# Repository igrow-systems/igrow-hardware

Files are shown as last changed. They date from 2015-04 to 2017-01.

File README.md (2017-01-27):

# README #

This README would normally document whatever steps are necessary to get your application up and running.

### What is this repository for? ###

* Quick summary
* Version
* [Learn Markdown](https://bitbucket.org/tutorials/markdowndemo)

### Prototype Hardware ###

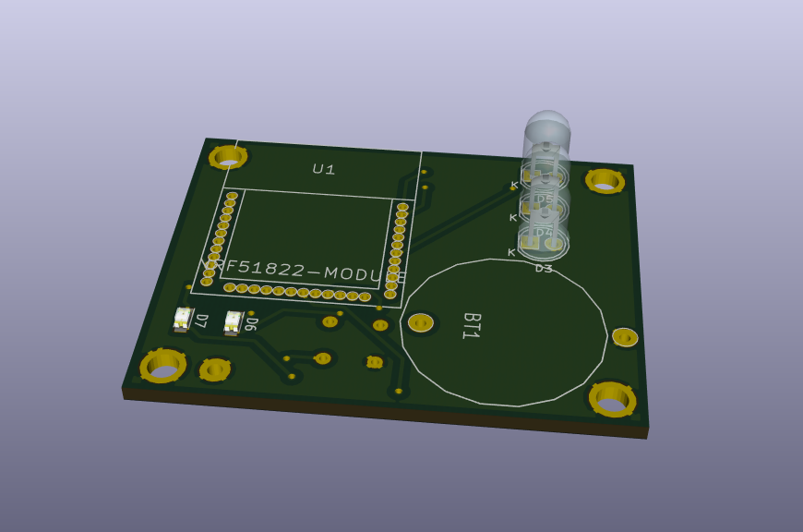
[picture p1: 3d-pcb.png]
PCB 3D View


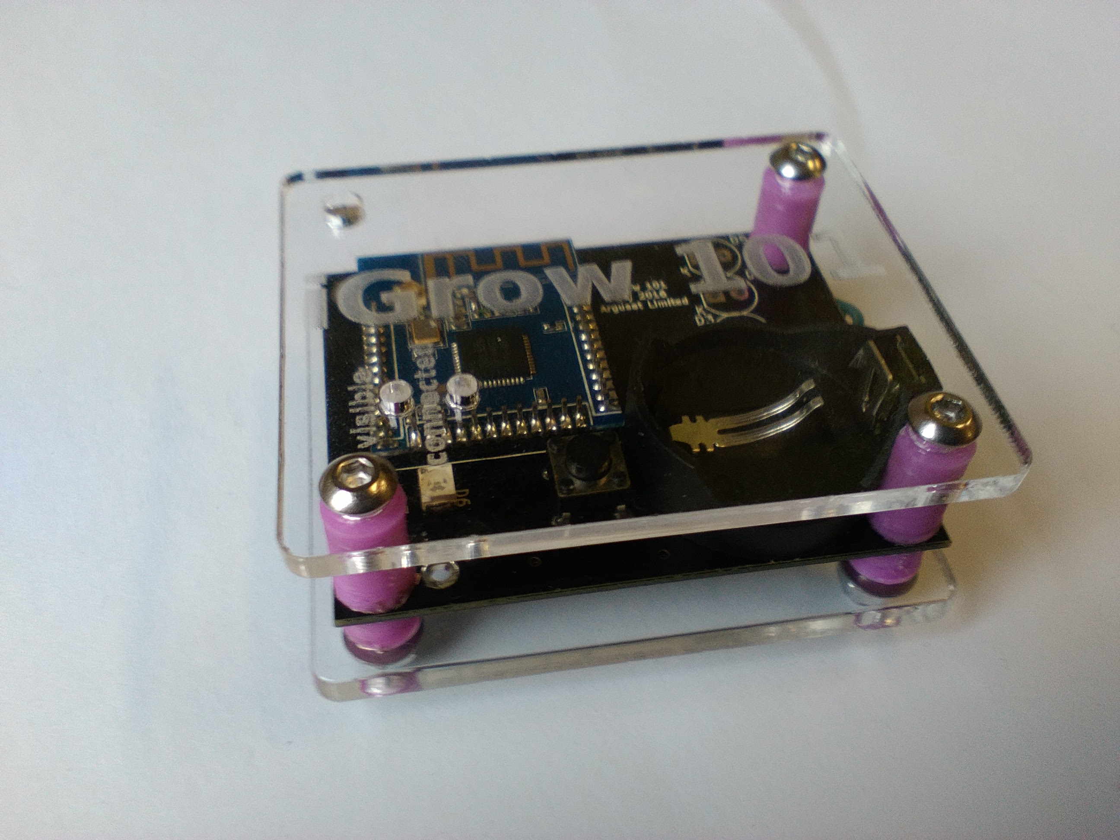
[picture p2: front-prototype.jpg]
Prototype Front


### How do I get set up? ###

* Summary of set up
* Configuration
* Dependencies
* Database configuration
* How to run tests
* Deployment instructions

### Contribution guidelines ###

* Writing tests
* Code review
* Other guidelines

### Who do I talk to? ###

* Repo owner or admin
* Other community or team contact

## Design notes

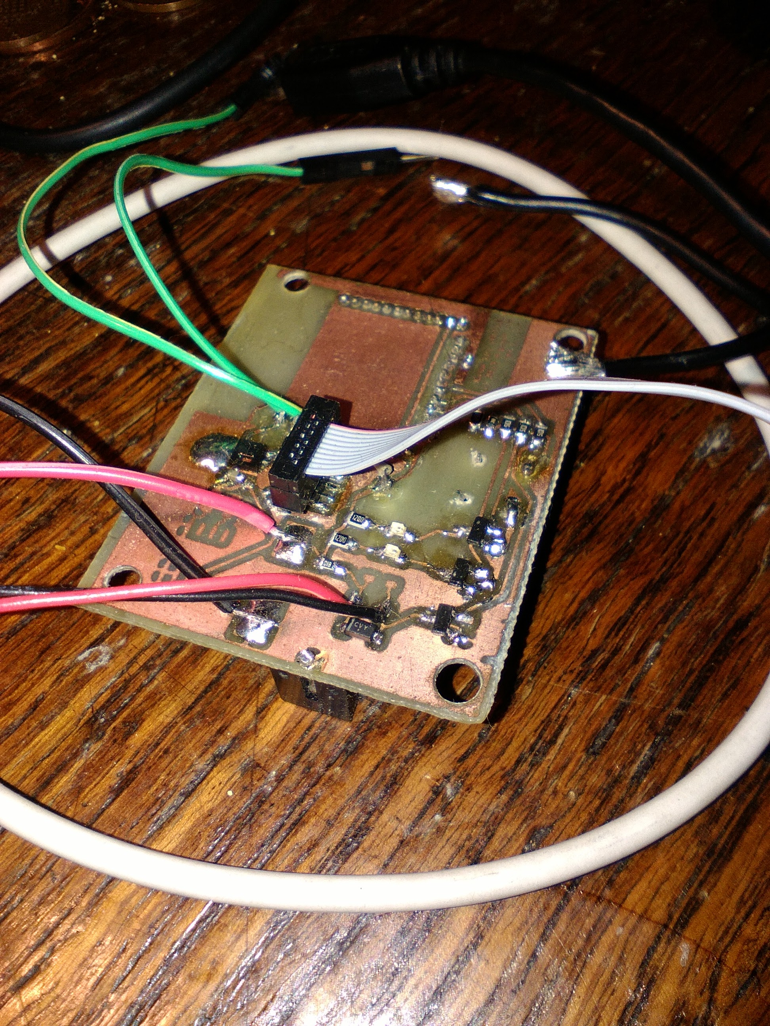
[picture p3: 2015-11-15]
rear-prototype.jpg

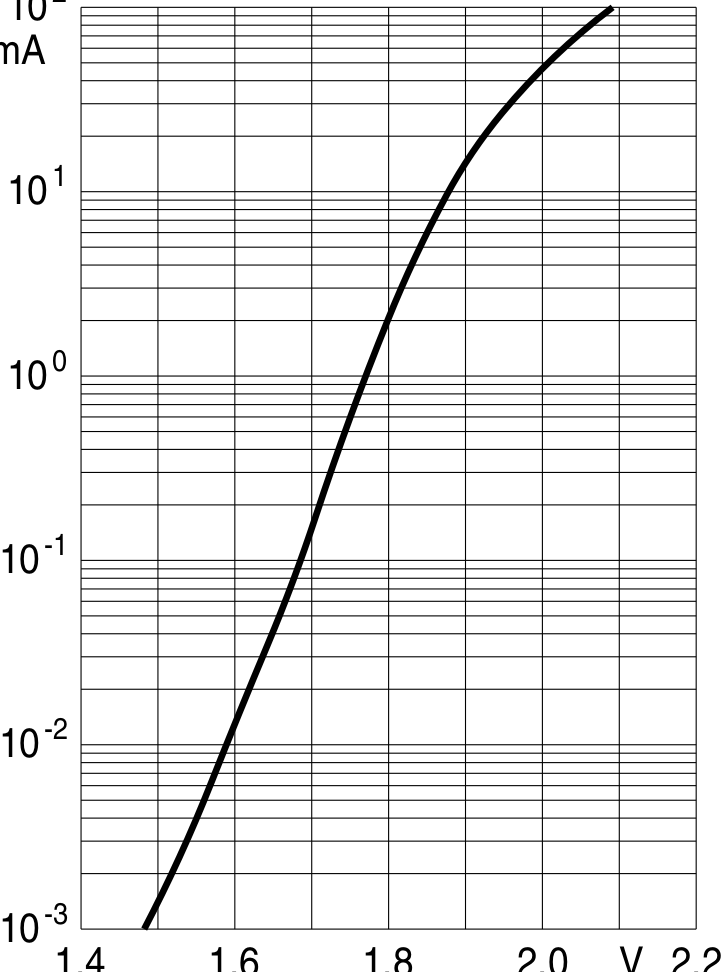
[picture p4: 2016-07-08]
sim/leds/osram_LGT67K_I_V.png

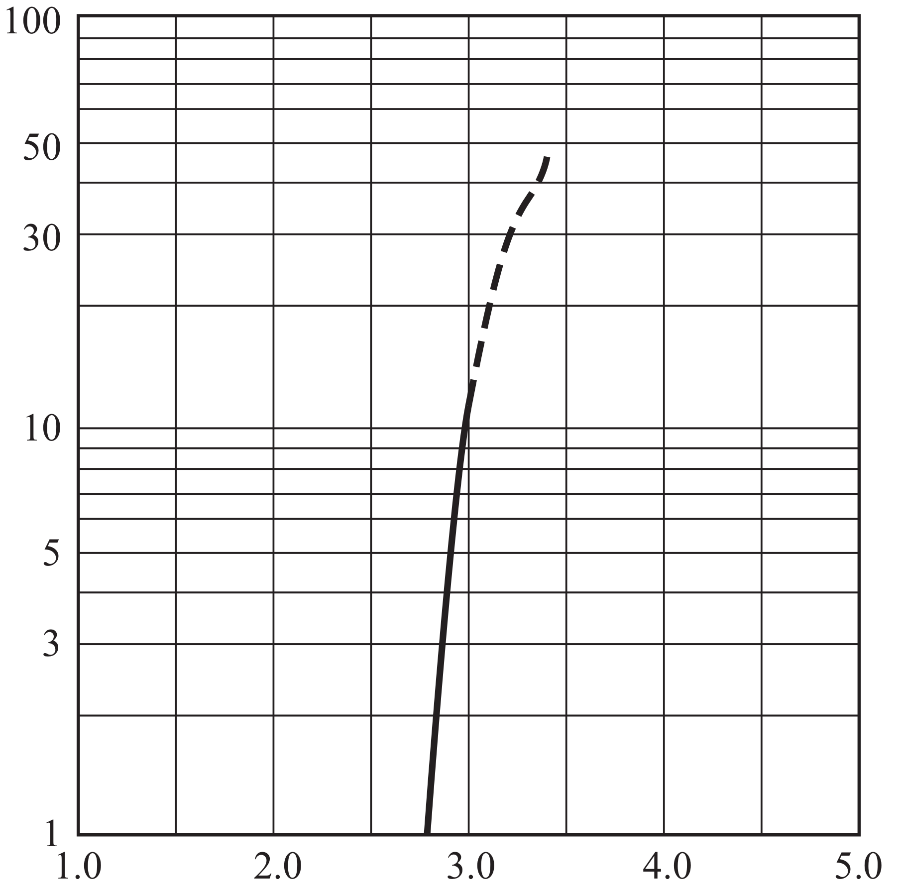
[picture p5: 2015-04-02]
sim/leds/LNJ953W8CRA_I_V.png

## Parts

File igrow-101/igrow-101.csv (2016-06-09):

Id | Designator | Package | Quantity | Designation | Supplier and ref
1 | C1 | C_0603_HandSoldering | 1 | C
2 | D1 | Diode-SMC_Handsoldering | 1 | DIODE
3 | R1,R2,R3,R4,R5,R6,R7,R8,R9,R10,R11,R12 | R_0603_HandSoldering | 12 | R
4 | SW1 | SPSTSW | 1 | SW_PUSH
5 | U1 | XL51822-D01 | 1 | NRF51822-MODULE
6 | U2 | SHT21 | 1 | SHT21
7 | BT1 | CR2032_THRUHOLE | 1 | BATTERY
8 | PIEZO1 | R_0805_HandSoldering | 1 | PIEZO
9 | P1 | harwin_m50-3600542 | 1 | CONN_02X05
10 | D2 | SOD123 | 1 | ZENER
11 | D3,D4,D5 | LED-5MM | 3 | LED
12 | P2,P3,P4,P5 | MountingHole_M3 | 4 | CONN_01X01
13 | Q1,Q2,Q3 | SOT-23_Handsoldering_EBC | 3 | NPN
14 | W1 | Measurement_Point_Round-TH_Big | 1 | TEST_1P
15 | D6,D7 | LED_0805 | 2 | LED

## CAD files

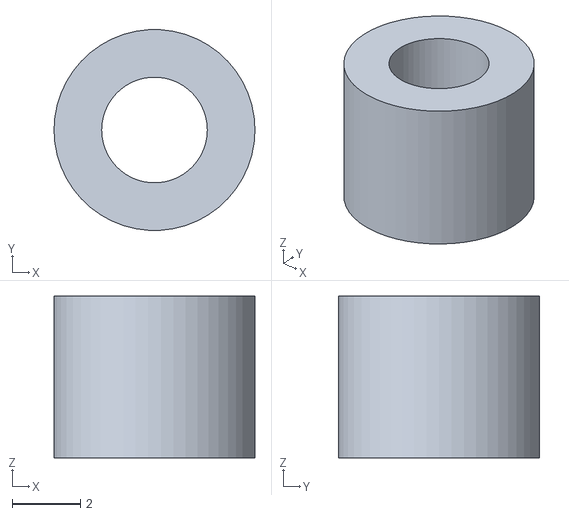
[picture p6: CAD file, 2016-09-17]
enclosure/stand-off-4.5mm.stl
5.90 x 5.89 x 4.75

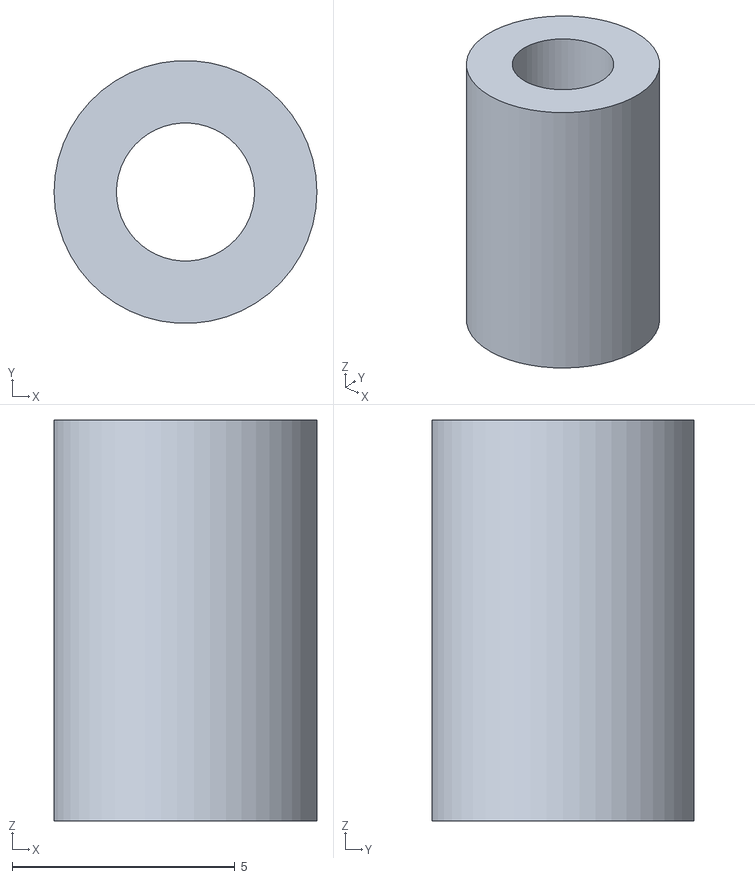
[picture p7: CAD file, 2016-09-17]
enclosure/stand-off-9.0mm.stl
5.90 x 5.89 x 9.00

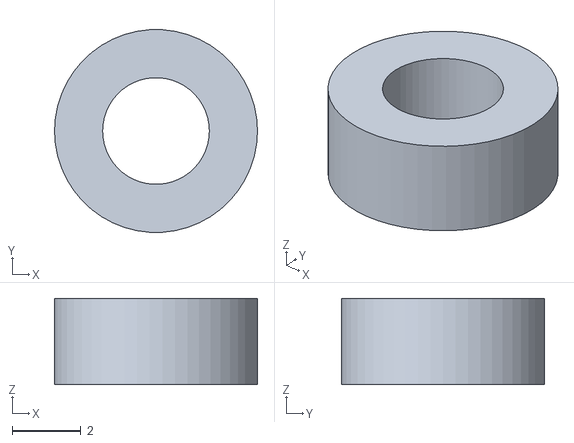
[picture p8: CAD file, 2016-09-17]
enclosure/stand-off-2.5mm.stl
5.90 x 5.89 x 2.50

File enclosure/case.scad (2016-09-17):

// *************************************************************************
/*
This program is free software: you can redistribute it and/or modify
it under the terms of the GNU General Public License as published by
the Free Software Foundation, either version 3 of the License, or
(at your option) any later version.

This program is distributed in the hope that it will be useful,
but WITHOUT ANY WARRANTY; without even the implied warranty of
MERCHANTABILITY or FITNESS FOR A PARTICULAR PURPOSE.  See the
GNU General Public License for more details.

You should have received a copy of the GNU General Public License
along with this program.  If not, see <http://www.gnu.org/licenses/>.
*/

// *************************************************************************

use <MCAD/polyholes.scad>;

// Box configuration
eps = 1.0;
wall_thickness         =   2.0;    // mm
box_external_length   = 81 + eps + wall_thickness * 2.0;    // mm
box_external_width    = 50 + eps + wall_thickness * 2.0;    // mm
box_external_height   =  5.0 + 2 * wall_thickness;    // mm
lid_tolerance          =   0.5;  // mm

// PCB mount configuration
// If pcb_mount_pos_vector set to describe mount positions then use this, if not set then rectangular with length pcb_mount_pitch_length and width pcb_mount_pitch_width
pcb_mount_pitch_length =  74.0;    // mm 
pcb_mount_pitch_width  =  43.0;    // mm
pcb_mount_pos_vec      = [[0,0],[0,43.0],[74.0, 35.0],[74.0, 0]];
pcb_mount_radius       =   1.5;  // mm
pcb_mount_height       =   4.0;    // mm
pcb_mount_insert_depth =   4;    // mm
pcb_mount_origin       = [(box_external_length - pcb_mount_pitch_length) - wall_thickness * 2.0, (box_external_width - pcb_mount_pitch_width) / 2.0]; // mm
pcb_mount_captive_nut_recess_radius = pcb_mount_radius * 2.0;
pcb_mount_captive_nut_recess_depth = 2.40 + 0.5;  // M3 nut plus 0.25mm fudge factor (each end)
pcb_mount_auto_centre  = true;
pcb_mount_captive_nut  = true;

// Lid mount configuration
lid_mount = false;
lid_mount_pitch_length =  box_external_length - wall_thickness * 2.0 - 10;   // mm
lid_mount_pitch_width  =  box_external_width - wall_thickness * 2.0 - 10;   // mm
lid_mount_radius       =   1.5;  // mm
lid_mount_height       =   box_external_height  - wall_thickness * 3.0;    // mm
lid_mount_insert_depth =   9.7;    // mm
lid_mount_origin       = [(box_external_length - lid_mount_pitch_length) / 2.0 + 5.0/* - (lid_mount_radius * 2.0 )*/, (box_external_width - lid_mount_pitch_width) / 2.0]; // mm
lid_hole_countersink = false;
lid_mount_auto_centre  = true;

// Mains socket?
mains_socket = false;
mains_socket_width = 28.5;  // mm
mains_socket_height = 20.5;  // mm
mains_socket_mount_pitch = 40.0; //mm
mains_socket_mount_d = 4.0;  //mm

// grommet?
grommet = false;
grommet_type = "rectangular";
grommet_width =  8.25;  // mm
grommet_height =  5.25;  // mm

// Screw holes throught the base ?
base_mount_holes = true;
base_mount_holes_pos_vec = [[0, 0], [25.4, 0]];
base_mount_holes_origin = [(box_external_length - 25.4) / 2.0/* - (lid_mount_radius * 2.0 )*/, (box_external_width - 0) / 2.0]; // mm;
base_mount_holes_radius  = 2.6;


// Style configuration
corner_style    = "rounded";  // only style currently available
rounding_radius = wall_thickness;
cylinder_faces  = 30;

logo           = false;
// Logo configuration
logo_thickness     =  2.5;
logo_size          = 30;
logo_corner_radius =  6;
logo_hole_radius   =  2;
logo_fn            = 30;
logo_origin        = [ 30, 20 ]; //mm

// Compute the expensive, albeit elegant Minkowski Sum 
// to generate the rounded box corners
use_minkowski = false;

use <../../SoMakeIt-Keyring/logo.scad>

union() {
           //!cylinder(r = 3.0 / cos(180 / 6), h = 3, $fn = 6);     
    // The lid
    %difference() {
        union() {
            translate ([wall_thickness + lid_tolerance,
                        wall_thickness + lid_tolerance,
                        box_external_height - 2.0 * wall_thickness]) {
                color("SeaGreen", a = 0.5) {
                    rounded_box(box_external_length - 2.0 * wall_thickness - 2.0 * lid_tolerance,
                                box_external_width - 2.0 * wall_thickness - 2.0 * lid_tolerance,
                                wall_thickness, rounding_radius);
                }
            }
            
            translate([0, 0, box_external_height - wall_thickness]) {
                rounded_box(box_external_length,
                        box_external_width,
                        wall_thickness, rounding_radius);
            }
            
            if (logo == true) {
                translate ([logo_origin[0], logo_origin[1], box_external_height]) {
                    somakeit_logo(logo_thickness, logo_size,
                                    logo_corner_radius, logo_hole_radius,
                                    logo_fn);
                }
            }
        }
        // The lid screw holes and countersinks
        if (lid_mount == true) {
            translate([0, 0, box_external_height - 1.0 * wall_thickness]) translate (lid_mount_origin) { 
                screw_holes(lid_mount_pitch_length,
                              lid_mount_pitch_width,
                              "undef",    // TODO: sort this horrible hack out by naming arguments
                              lid_mount_radius,
                              wall_thickness,
                              lid_hole_countersink);
            }
        }
        
        translate ([wall_thickness * 2.0 + lid_tolerance,
                        wall_thickness * 2.0 + lid_tolerance,
                        box_external_height - 2.0 * wall_thickness]) {
                color("SeaGreen", a = 0.5) {
                    rounded_box(box_external_length - 4.0 * wall_thickness - lid_tolerance,
                                box_external_width - 4.0 * wall_thickness - lid_tolerance,
                                wall_thickness, rounding_radius);
                }
            }
    }
    
    // The main body of the box
    difference() {
        rounded_box(box_external_length,
                    box_external_width,
                    box_external_height - wall_thickness,
                    rounding_radius);
    
        translate ([wall_thickness, wall_thickness, wall_thickness]) {
            rounded_box(box_external_length - 2.0 * wall_thickness,
                        box_external_width - 2.0 * wall_thickness,
                        box_external_height - 2.0 * wall_thickness,
                        rounding_radius);
        }
        
        // Mains socket cutout
        if (mains_socket) {
            union() {
                translate([wall_thickness / 2.0 - 1.0, box_external_width / 2.0, box_external_height / 2.0]) {
                    cube([wall_thickness + 2.0, mains_socket_width, mains_socket_height], center=true);
                    translate ([-wall_thickness / 2.0, -mains_socket_mount_pitch / 2.0, 0]) rotate([0,90,0]) polyhole(d = mains_socket_mount_d, h = wall_thickness + 2.0);
                    translate ([-wall_thickness / 2.0, mains_socket_mount_pitch / 2.0, 0]) rotate([0,90,0]) polyhole(d = mains_socket_mount_d, h = wall_thickness + 2.0);
                }
            }
        }
        
        if (grommet) {
            if (grommet_type == "rectangular") {
                translate([box_external_length - wall_thickness / 2.0 + 1.0, box_external_width / 2.0, wall_thickness + 12.0]) {
                    cube([wall_thickness + 2.0, grommet_width, grommet_height], center=true);
                }
            }
        }
        
        // Base mount holes
        if (base_mount_holes)  {
            translate (base_mount_holes_origin) { 
                    screw_holes(pcb_mount_pitch_length,
                                pcb_mount_pitch_width,
                                base_mount_holes_pos_vec,
                                base_mount_holes_radius,
                                wall_thickness,
                                true);
            }
        }
        
               // PCB mount nut recesses
        if (pcb_mount_captive_nut) {
            if (pcb_mount_auto_centre) {
                pcb_mount_origin = [ (box_external_length - pcb_mount_pitch_length) / 2.0, (                box_external_width - pcb_mount_pitch_width) / 2.0];
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

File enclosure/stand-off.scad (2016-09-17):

$fn = 50;

difference() {
    cylinder(r = 2.95, h = 2.5);
    cylinder(r = 1.55, h = 2.5);
}

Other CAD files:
enclosure/stand-off.stl

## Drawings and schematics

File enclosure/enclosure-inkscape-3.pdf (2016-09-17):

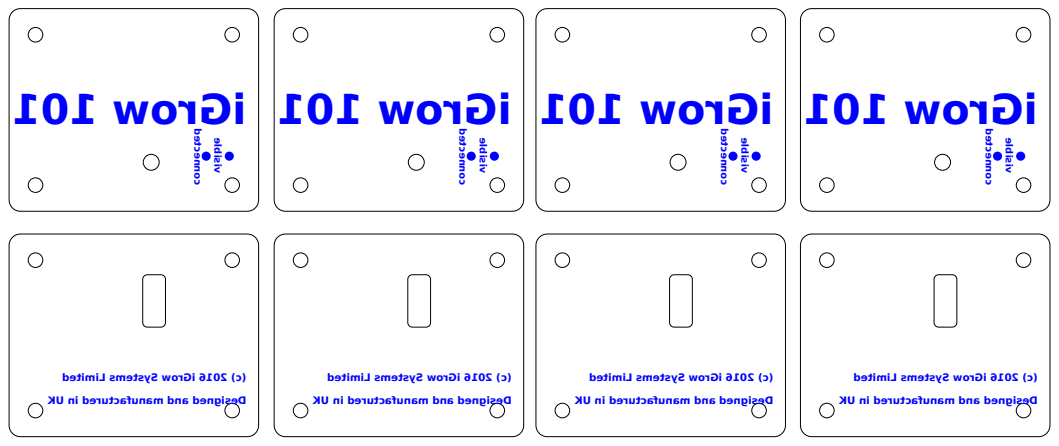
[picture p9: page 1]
visible; connected

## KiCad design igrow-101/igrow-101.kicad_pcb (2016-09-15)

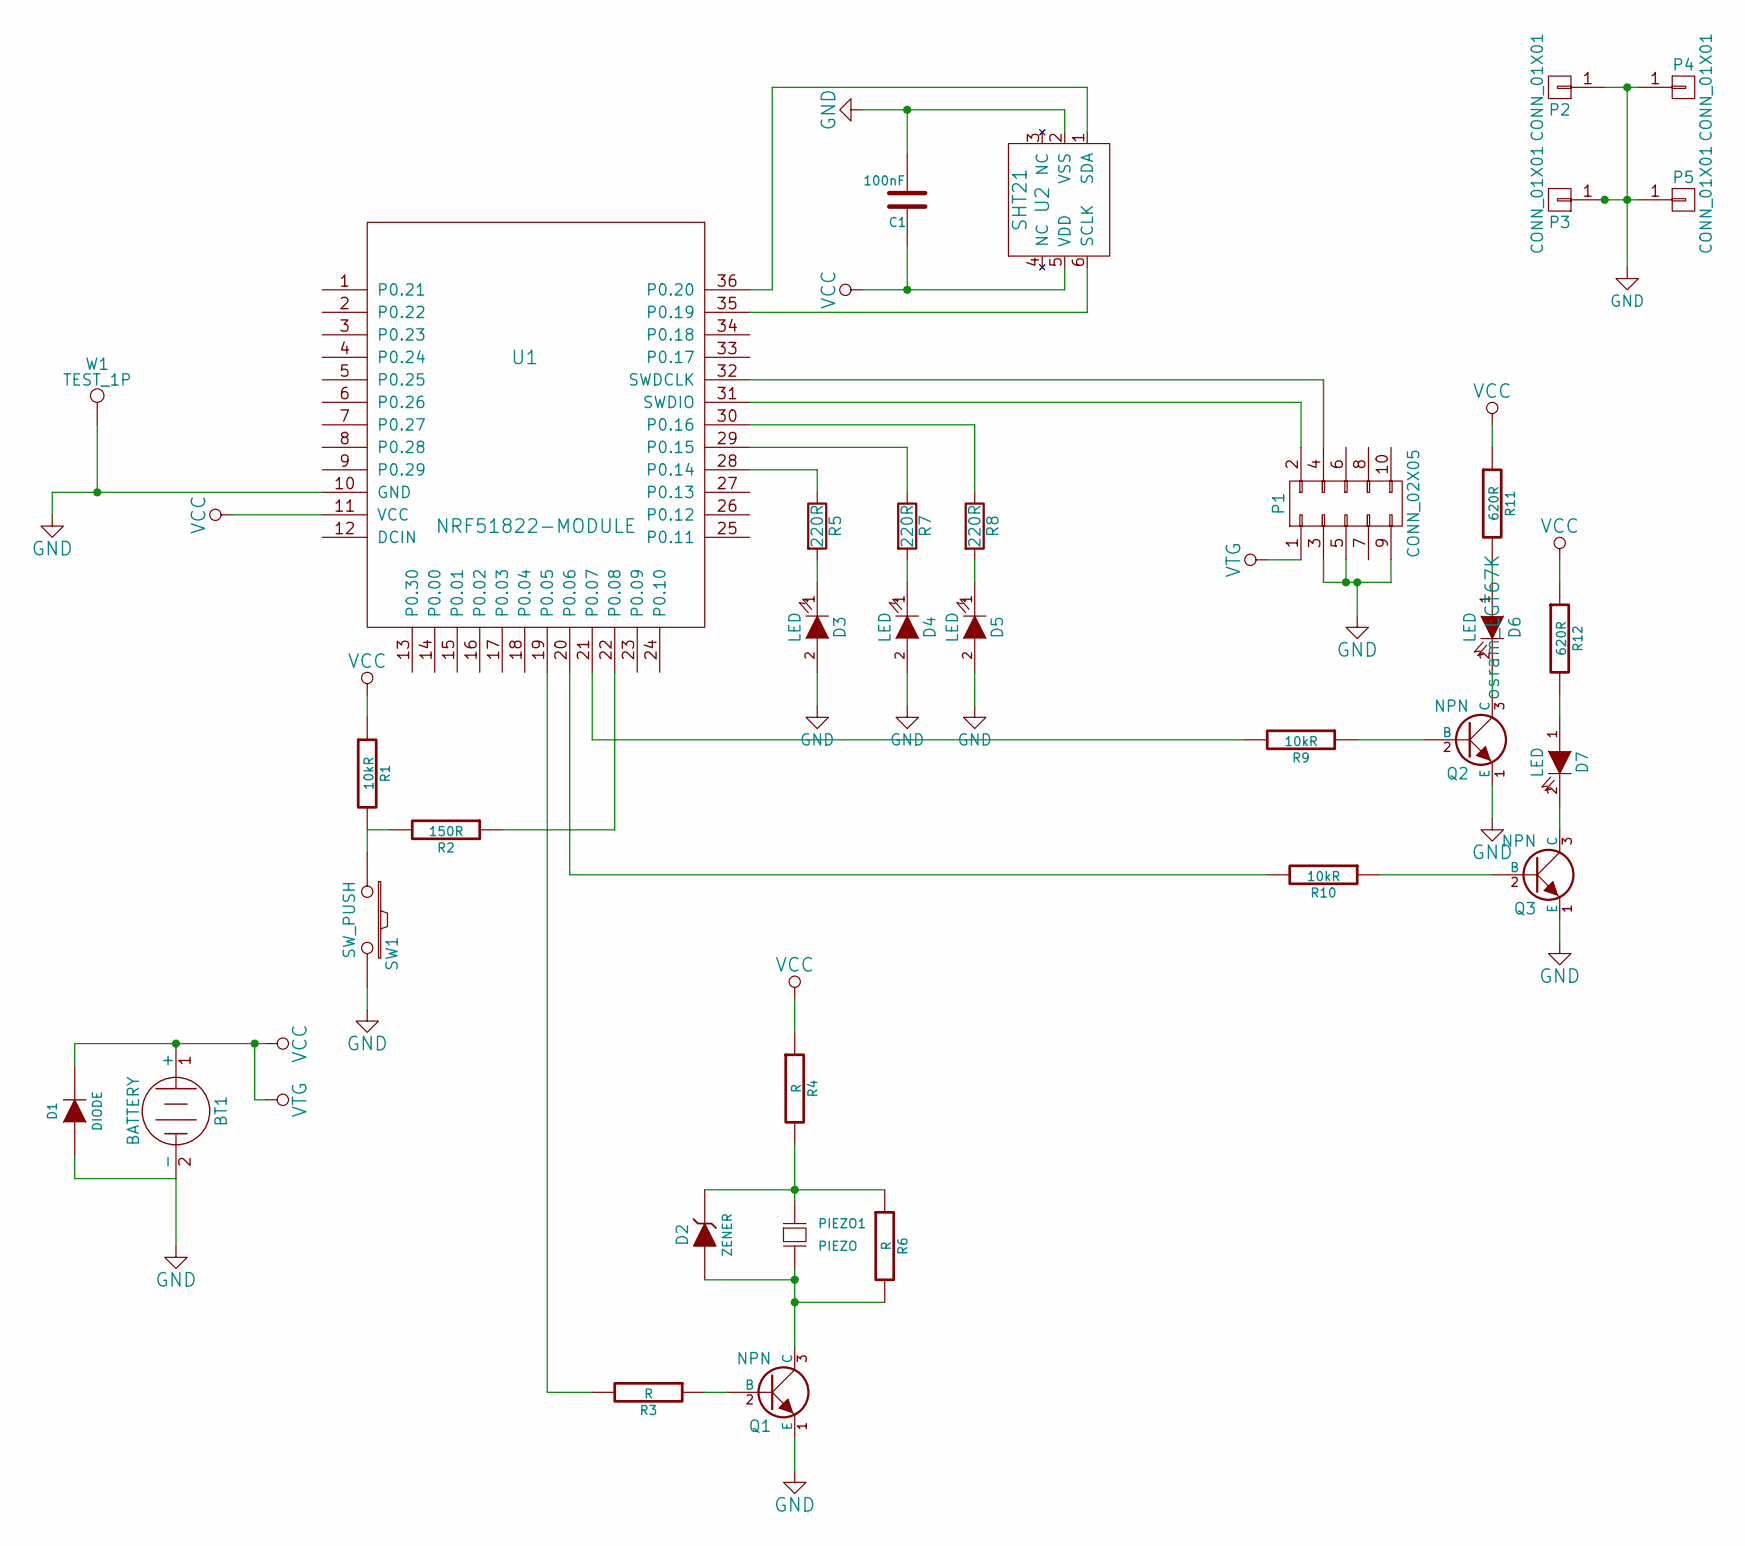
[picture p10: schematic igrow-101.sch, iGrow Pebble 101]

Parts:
BT1: BATTERY; CR2032_THRUHOLE
C1: 100nF; C_0603_HandSoldering
D1: DIODE; Diode-SMC_Handsoldering
D2: ZENER; SOD123
D3, D4, D5: LED; LED-5MM
D6, D7: LED; LED_0805
P1: CONN_02X05; harwin_m50-3600542
P2, P3, P4, P5: CONN_01X01; MountingHole_M3
PIEZO1: PIEZO; R_0805_HandSoldering
Q1, Q2, Q3: NPN; SOT-23_Handsoldering_EBC
R1, R9, R10: 10kR; R_0603_HandSoldering
R2: 150R; R_0603_HandSoldering
R3, R4, R6: R; R_0603_HandSoldering
R5, R7, R8: 220R; R_0603_HandSoldering
R11, R12: 620R; R_0603_HandSoldering
SW1: SW_PUSH; SPSTSW
U1: NRF51822-MODULE; XL51822-D01
U2: SHT21; SHT21_HandSoldering
W1: TEST_1P; Measurement_Point_Round-TH_Big

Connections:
GND: BT1.2 (-), C1.2, D1.1 (A), D3.2 (A), D4.2 (A), D5.2 (A), P1.3, P1.5, P1.9, P2.1, P3.1, P4.1, P5.1, Q1.1 (E), Q2.1 (E), Q3.1 (E), SW1.2, U1.10 (GND), U2.2 (VSS), W1.1
unnamed: D2.1 (A), PIEZO1.2, Q1.3 (C), R6.2
unnamed: D2.2 (K), PIEZO1.1, R4.2, R6.1
unnamed: D3.1 (K), R5.2
unnamed: D4.1 (K), R7.2
unnamed: D5.1 (K), R8.2
unnamed: D6.1 (A), R11.2
unnamed: D6.2 (K), Q2.3 (C)
unnamed: D7.1 (A), R12.2
unnamed: D7.2 (K), Q3.3 (C)
unnamed: P1.2, U1.31 (SWDIO)
unnamed: P1.4, U1.32 (SWDCLK)
unnamed: Q1.2 (B), R3.1
unnamed: Q2.2 (B), R9.1
unnamed: Q3.2 (B), R10.1
unnamed: R1.2, R2.2, SW1.1
unnamed: R2.1, U1.22 (P0.08)
unnamed: R3.2, U1.19 (P0.05)
unnamed: R5.1, U1.28 (P0.14)
unnamed: R7.1, U1.29 (P0.15)
unnamed: R8.1, U1.30 (P0.16)
unnamed: R9.2, U1.21 (P0.07)
unnamed: R10.2, U1.20 (P0.06)
unnamed: U1.35 (P0.19), U2.6 (SCLK)
unnamed: U1.36 (P0.20), U2.1 (SDA)
VCC: BT1.1 (+), C1.1, D1.2 (K), P1.1, R1.1, R4.1, R11.1, R12.1, U1.11 (VCC), U2.5 (VDD)

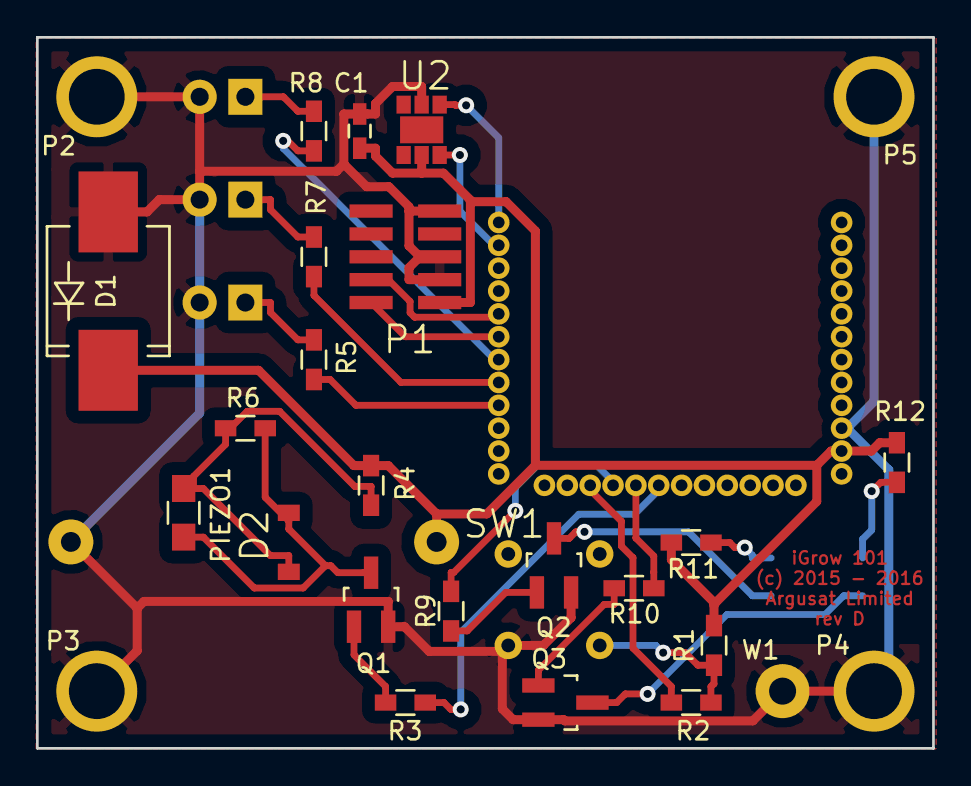
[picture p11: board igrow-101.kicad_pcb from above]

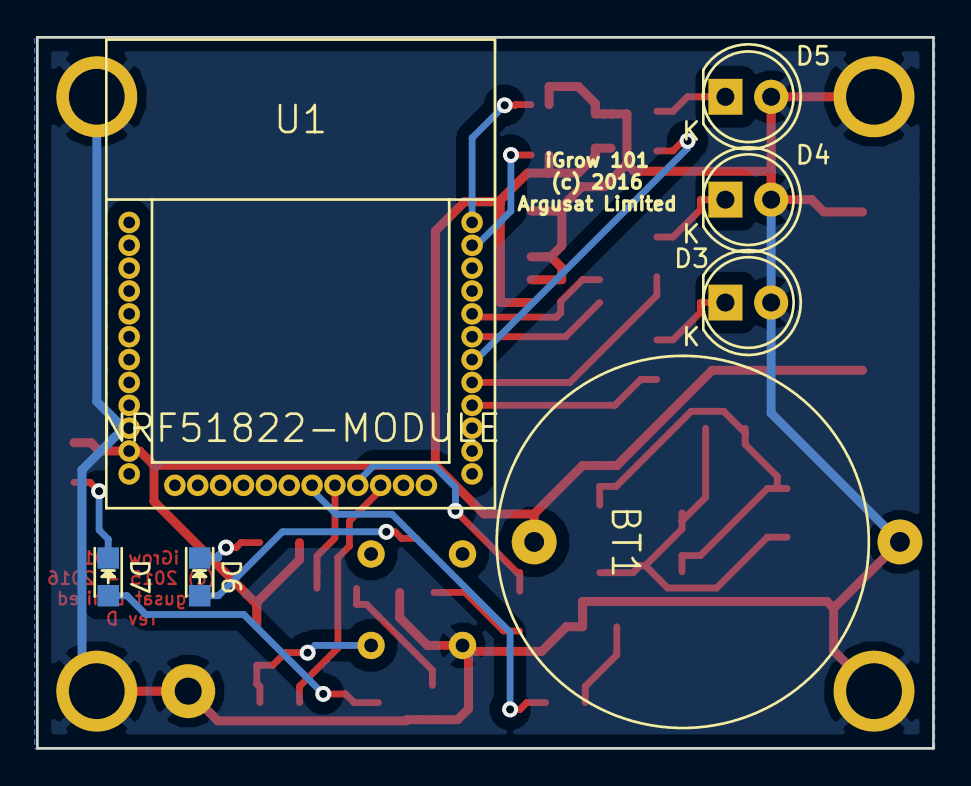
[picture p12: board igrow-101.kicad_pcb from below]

Board: 2 copper layers, 49.8 x 39.5 mm, 34 parts (7 on the bottom side), 26 nets.

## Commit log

2015-04-02 Add simulation work and schematic/board WIP
    [LNJ953W8CRA_I_V.csv, igrow-101.dsn, igrow-101.kicad_pcb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]
2015-04-06 Post autorouting
    [$igrow-101.sch, igrow-101-postroute.dsn, igrow-101.dsn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]
2015-04-06 First attempt at cooking a board...
    [igrow-101.kicad_pcb]
2015-04-11 Flip module to other side, correct header pinout and make the module pads bigger
    [$igrow-101.sch, igrow-101.dsn, igrow-101.kicad_pcb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]
2015-04-13 Make module copper pads a bit larger
    [igrow-101.kicad_pcb]
2015-04-13 Rework with 0.381mm minimum track widths
    [igrow-101.dsn, igrow-101.kicad_pcb]
2015-04-13 Rework with 0.508mm/20mil minimum track widths
    [igrow-101.kicad_pcb]
2015-04-20 Move library dependency local to this repository for now.
    [igrow-101.sch]
2015-11-15 Add photos. Update svgs
    [igrow-101.sch]
2015-11-15 Add PCB 3d render
2016-06-08 First pass at board revision D - use direct connected IR LEDs for sensing
    [igrow-101.dsn, igrow-101.kicad_pcb, igrow-101.sch]
2016-06-09 Revision D as sent to dirtypcbs for fab
    [igrow-101-B.Cu.gbl, igrow-101-B.Mask.gbs, igrow-101-B.Paste.gbp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]
2016-07-08 Add simulation updates for osram_LGT67K LED. Not sure why there is a changed polygon in the pcb file...
    [igrow-101.kicad_pcb, osram_LGT67K_I_V.csv, osram_LGT67K_sim.sch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]
2016-07-10 Fix diode calibrator script. Add updated LED model. Add calculated schematic values. Add Matlab/octave scripts for plotting simulation output.
    [igrow-101.sch, osram_LGT67K_sim_diode_only.sch]
2016-08-28 Make nRF51822 module through-holes larger, battery holder through-holes larger. Make pads for SHT21 device larger.
2016-08-28 Correct sizing for module, button cell holder through-holes and enlarge SHT21 pads to allow hand soldering if required.
    [igrow-101.dsn, igrow-101.kicad_pcb, igrow-101.sch]
2016-09-15 Hardware revision F
    [igrow-101-B.Cu.gbl, igrow-101-B.Mask.gbs, igrow-101-B.Paste.gbp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]
2016-09-17 Add enclosure script and output for laser cutting.
    [case.scad, stand-off-2.5mm.stl, stand-off-4.5mm.stl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]
2017-01-27 Update prototype photo.

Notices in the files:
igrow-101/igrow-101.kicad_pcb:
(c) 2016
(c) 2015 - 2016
